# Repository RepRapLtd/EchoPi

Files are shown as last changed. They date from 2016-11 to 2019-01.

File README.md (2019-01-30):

# EchoPi

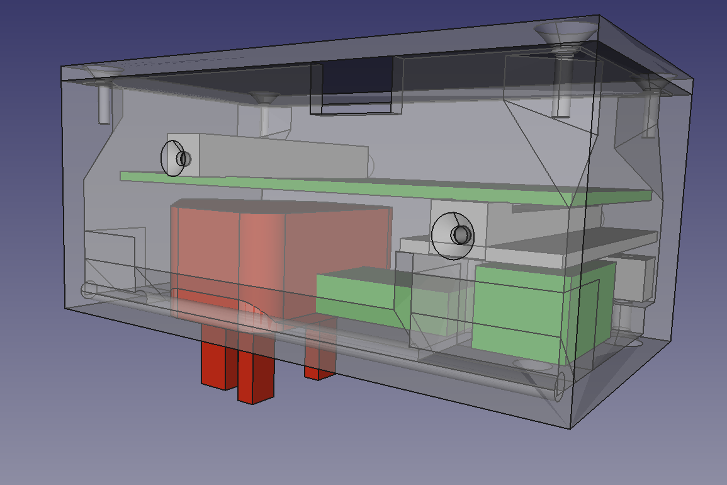
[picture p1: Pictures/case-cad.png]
FreeCAD design


This is a device that uses the Raspberry Pi Zero as a WeMo device to turn on mains-powered items in your home using the Amazon Echo/Echo-Dot and their Alexa voice-recognition system.

## Safety

This uses mains electricity.  Mains will kill you if you touch it.  So don't.

The maximum current that this can switch is 1 amp.  With 220-volt mains that means a maximum 200W load; with 110-volt mains that means a maximum 100 W load.  The device is designed with a fuse holder.  Fit this with a 1 A fuse.

Parents: we set no age limits here - there are twelve-year-olds who could have organised D-Day, and there are thirty-seven-year-olds who can't be trusted with a penknife.  But don't let your children experiment with this unless you are confident that they are responsible and sensible.

Realistically, you will probably want to operate this with the cover off when you are setting it up.  Plug everything in to a disconnected extension cable and connect everything up.  Then - without touching anything to do with the uncovered case - plug the extension into a wall socket and turn it on.  Turn off and unplug the wall socket before you touch anything again.

## Electronics

The Eagle (https://cadsoft.io/) circuit design is single sided with a few jumpers.  It is intended to be produced by milling, though you can etch it conventionally as well of course.

The device incorporates a mains USB charger (like this: https://www.amazon.co.uk/Quality-Charger-Blackberry-Love-Accessories/dp/B01M2XE8V9/ ; red in the picture above).  This both acts as the plug so the device can be plugged into a wall socket, and as a 5V supply for the Raspberry Pi Zero and the rest of the electronics.

You will have to hack the charger by attaching wires to the three mains connections inside and drilling holes to run them out of.  The neutral and earth run straight through the device to the mains output, and the live wire goes through the fuse and then the opto-isolated phototriac, which switches it on and off.   

## Mechanics

The FreeCAD (http://www.freecadweb.org/) case is designed to be 3D printed.  

## Software

See here to create a linux image on an SD card for the Pi Zero:

https://www.raspberrypi.org/documentation/installation/installing-images/linux.md

Boot up the Pi Zero.  Change it's name to something you want:

http://www.howtogeek.com/167195/how-to-change-your-raspberry-pi-or-other-linux-devices-hostname/

Set your timezone:

http://www.geeklee.co.uk/update-time-zone-on-raspberry-pi-with-raspbian/

Set your Pi to have a static IP address, giving it the same one for ethernet and WiFi (you're not going to use both at once):

https://www.modmypi.com/blog/how-to-give-your-raspberry-pi-a-static-ip-address-update

Setup your WiFi network and password:

https://learn.adafruit.com/adafruits-raspberry-pi-lesson-3-network-setup/setting-up-wifi-with-occidentalis

Next get and run the EchoPi software:

$ git clone https://github.com/RepRapLtd/EchoPi.git

$ cd EchoPi/Software

$ pip install -r requirements.txt

$ nohup python echopi.py > /dev/null &

Tell Alexa, "Alexa, discover my devices."

Say, "Alexa, turn off device," and, "Alexa device on," to switch the mains socket off and on.

The line in the Python echopi.py program that sets the Alexa name of the device is this one:

     TRIGGERS = {"device": 52000}

Change the "device" to any name you like, but it's best to choose easily-pronounceable dictionary words or well-known proper nouns.  That way the Alexa speech recognition will be most reliable.

This is intended to connect to your home network using WiFi, but (particularly with BT HomeHubs) getting your Echo/Echo-Dot to find the device can be tricky.  

Start by turning off all the annoying "features" of the BT hub: disable Smart Setup; don't synchronise 5 GHz WiFi with 2.4 GHz (keep the passwords the same, though, or you'll never remember, and ignore the password warning it gives you when you do this); turn off Extended UPnP security.

Then use a micro-USB-to-ether adapter to connect the Pi Zero by wire to your hub.  

Run the Python program and tell Alexa to discover your devices.  She should find "device" (or whatever you have called it).  Test that it works by turning the load on and off.

Then shut everything down and disconnect it.  Fit a micro-USB-WiFi adapter in place of the Ethernet and power everything up again.  You should be able to ssh into the Pi as before.

Ask Alexa to turn your device on.  If she sees it, great.  But if not, press and hold the Echo/Echo-dot button to put it into set-up mode and leave it for a minute or so, then press and hold it again to turn set-up off.  It should reconnect to your hub and then be able to turn your device on and off.

The "nohup python echopi.py > /dev/null &" command will run the Python program in the background and it will stay running until you re-boot the Pi.  If you want to see what it is doing, just run "python echopi.py" instead.  But this will die when you log out.

If the program is running in the background and you want to kill it and start again, type:

$ ps -ael | grep pyth

This will give something like:

  0 S  1000   868   834 41  80   0 -  4062 poll_s pts/0    00:00:02 python

The number of the Python process is the 868.  To stop process 868 type:

$ kill -9 868

## Useful Links

Turn a Pi into an Echo/Echo-Dot equivalent:

http://www.instructables.com/id/Hacking-the-Amazon-Echo/

WeMo - the protocol used:

https://www.wemo.com/

## Acknowledgements

This is an extended fork of Todd Medema's repository here:

https://github.com/toddmedema/echo

Many thanks to him.

It uses the Raspberry Pi Zero Eagle Library from here:

https://www.raspberrypi.org/forums/viewtopic.php?f=63&t=127228

So thanks to them too.

## Licence

GPL

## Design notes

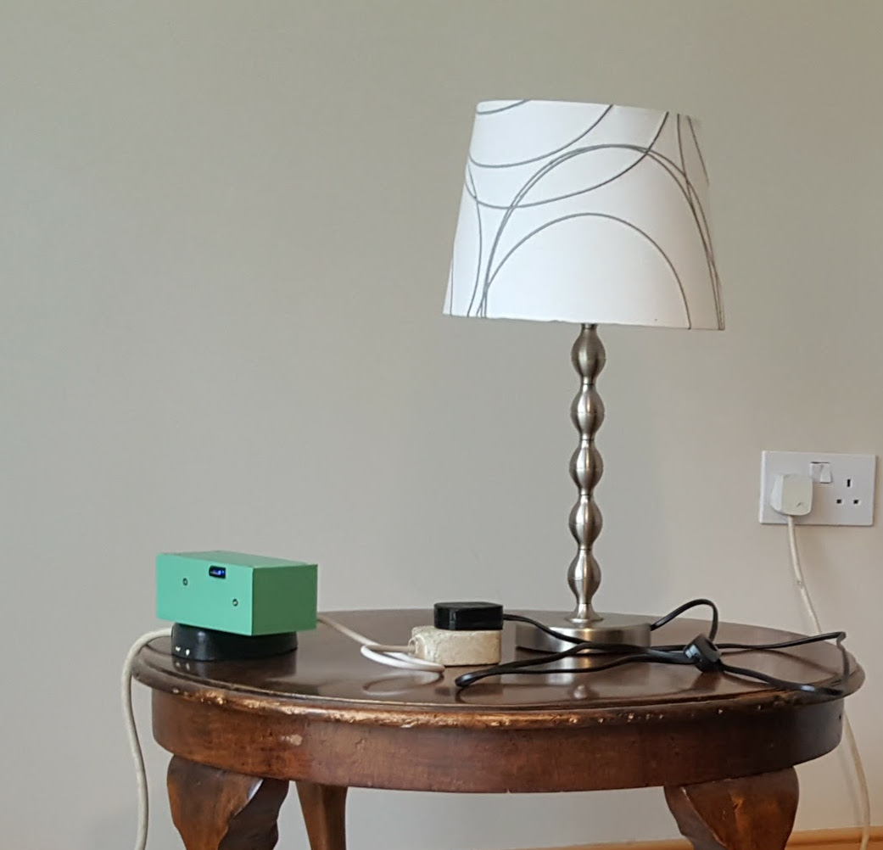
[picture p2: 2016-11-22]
Pictures/in-use.jpg

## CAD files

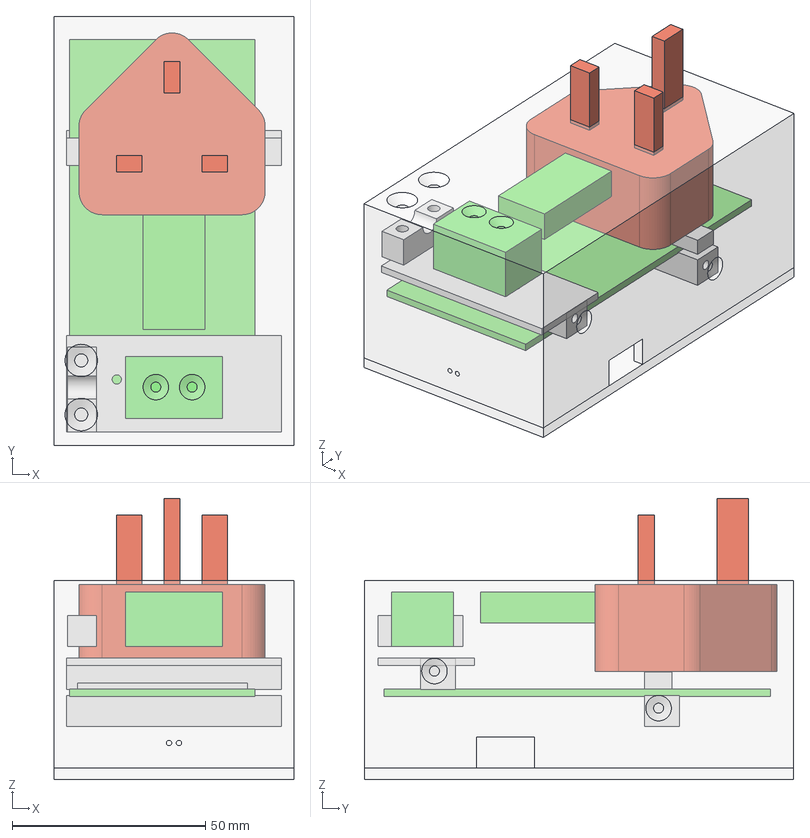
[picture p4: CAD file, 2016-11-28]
Mechanics/echopi.fcstd
62.0 x 111.0 x 72.8 mm
pcb
USB-A-plug
screw-con
cable-clamp
lid
13A-charger
pcb-support-2
spacer
pcb-support-1

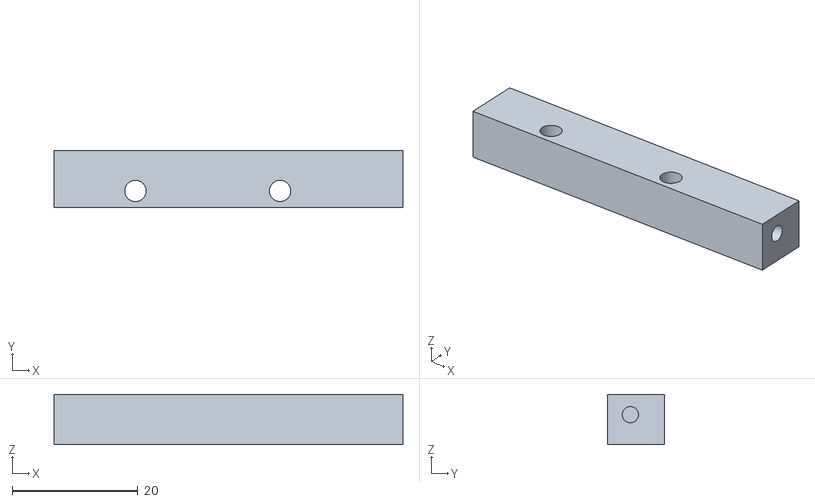
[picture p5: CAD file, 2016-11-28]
Mechanics/STLs/pcb-support-1.stl
55.5 x 9.00 x 8.00

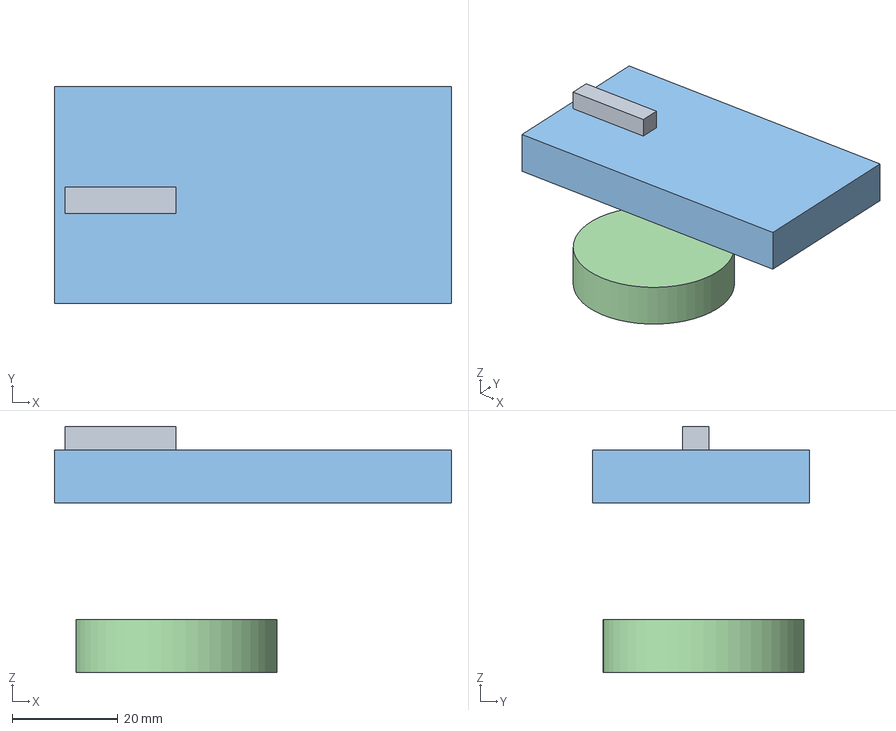
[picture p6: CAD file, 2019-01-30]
WeMos/Plug Box.fcstd
75.0 x 41.0 x 46.5 mm

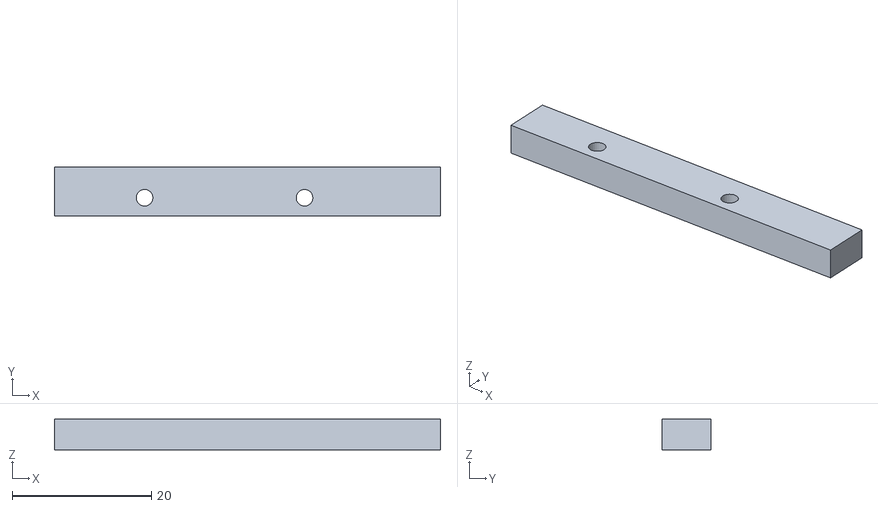
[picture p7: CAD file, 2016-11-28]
Mechanics/STLs/spacer.stl
55.5 x 7.00 x 4.40

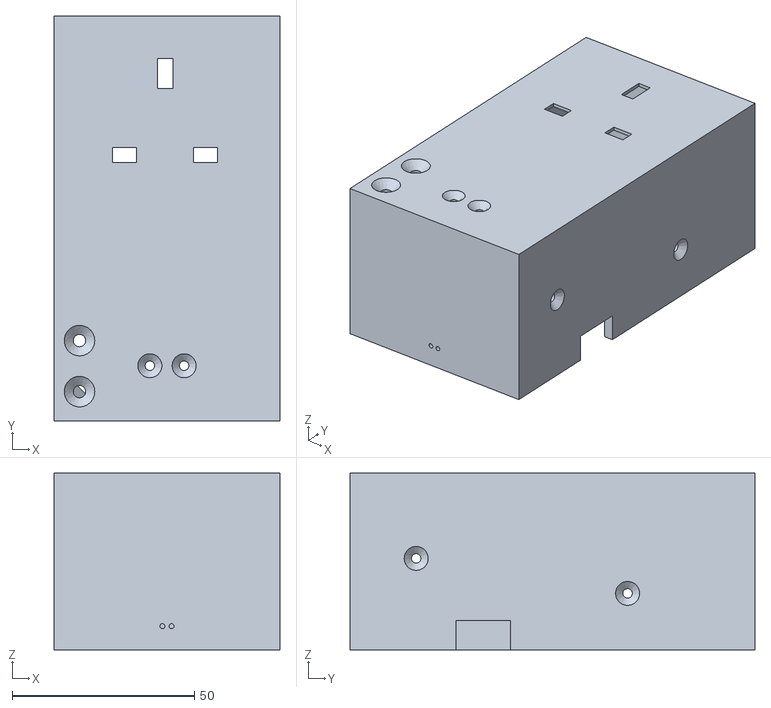
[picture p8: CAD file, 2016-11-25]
Mechanics/STLs/body.stl
62.0 x 111.0 x 48.5

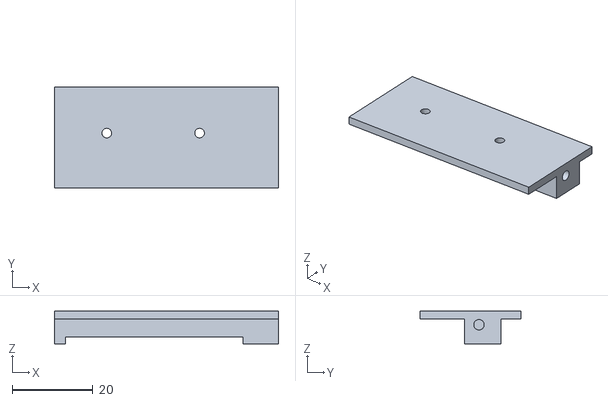
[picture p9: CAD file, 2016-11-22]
Mechanics/STLs/pcb-support-2.stl
55.5 x 25.0 x 8.17

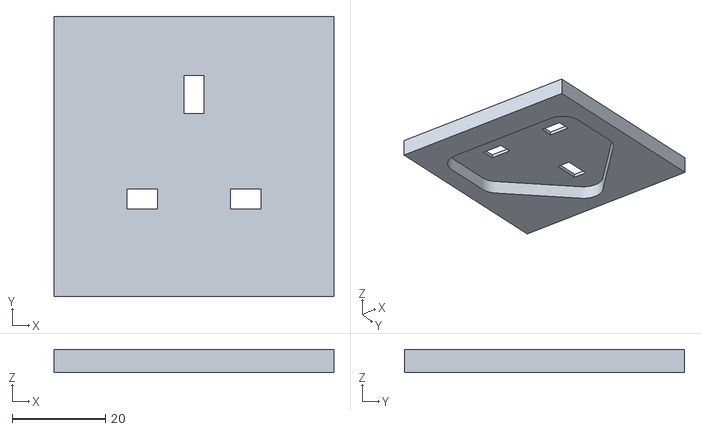
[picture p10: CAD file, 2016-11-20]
Mechanics/STLs/plug-test.stl
60.0 x 60.0 x 5.00

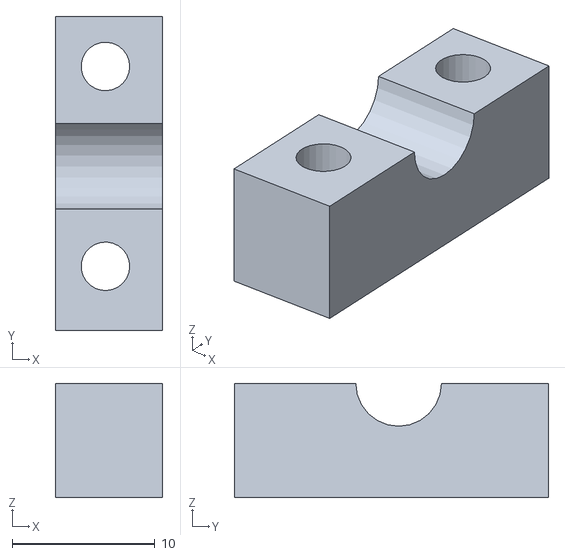
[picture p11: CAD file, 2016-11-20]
Mechanics/STLs/cable-clamp.stl
7.50 x 22.0 x 8.00

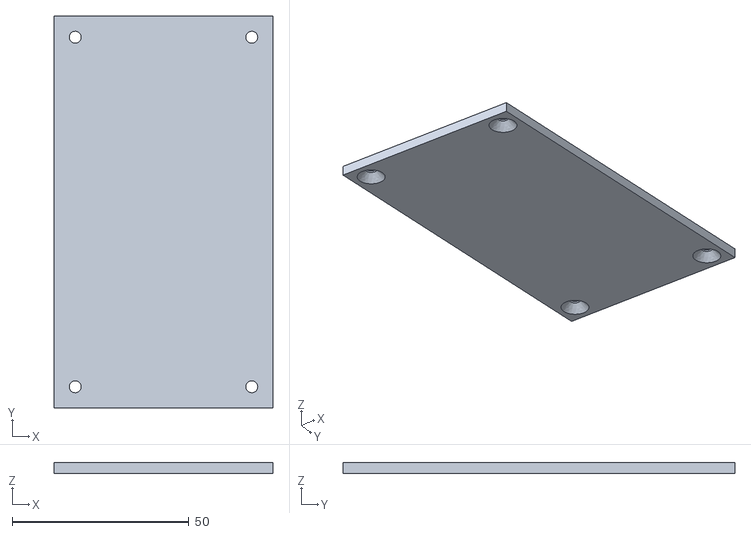
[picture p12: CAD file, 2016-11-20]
Mechanics/STLs/lid.stl
62.0 x 111.0 x 3.00

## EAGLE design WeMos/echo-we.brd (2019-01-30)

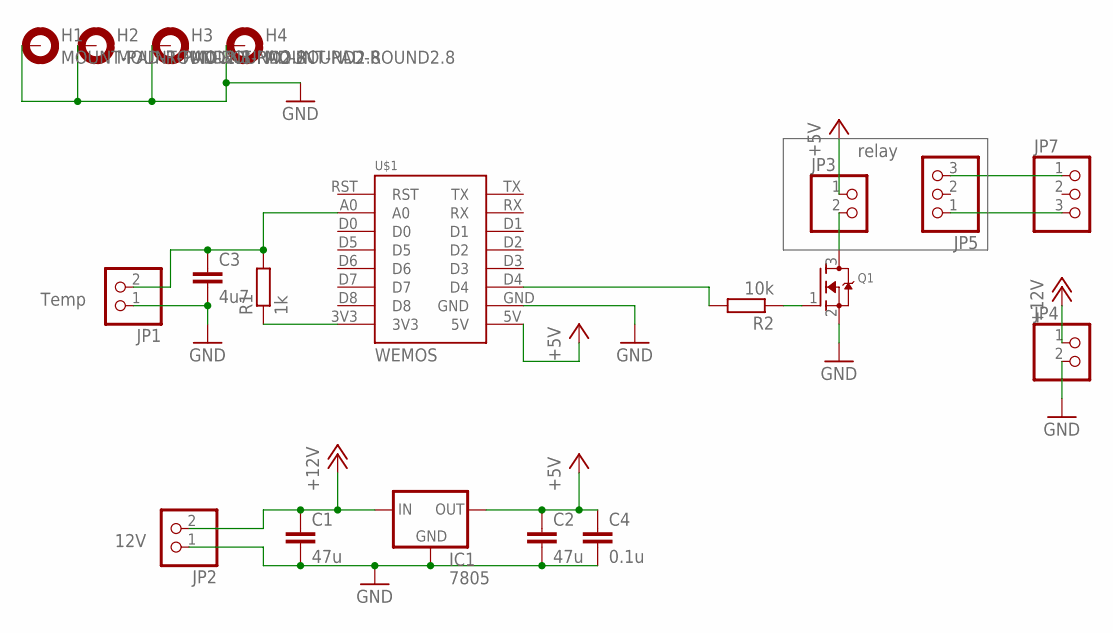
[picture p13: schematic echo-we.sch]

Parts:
C1, C2: 47u; C1206
C3: 4u7; C1206
C4: 0.1u; C1206
H1, H2, H3, H4: MOUNT-PAD-ROUND2.8; 2,8-PAD
IC1: 7805; 78XXS
JP1, JP2, JP3, JP4: PINHD-1X2; 1X02
JP5, JP7: PINHD-1X3; 1X03
Q1: MOSFET-NREFLOW; SOT23
R1: 1k; R0805
R2: 10k; R0805
U$1: WEMOS

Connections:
+5V: C2.1, C4.1, IC1.OUT, JP3.1, U$1.5V
+12V: C1.1, IC1.IN, JP2.2, JP4.1
GND: C1.2, C2.2, C3.2, C4.2, H1.B2,8, H2.B2,8, H3.B2,8, H4.B2,8, IC1.GND, JP1.1, JP2.1, JP4.2, Q1.2 (S), U$1.GND
unnamed: R1.1, U$1.3V3
unnamed: C3.1, JP1.2, R1.2, U$1.A0
unnamed: JP5.3, JP7.1
unnamed: JP5.1, JP7.3
unnamed: R2.2, U$1.D4
unnamed: Q1.1 (G), R2.1
unnamed: JP3.2, Q1.3 (D)

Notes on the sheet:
Temp
12V
relay

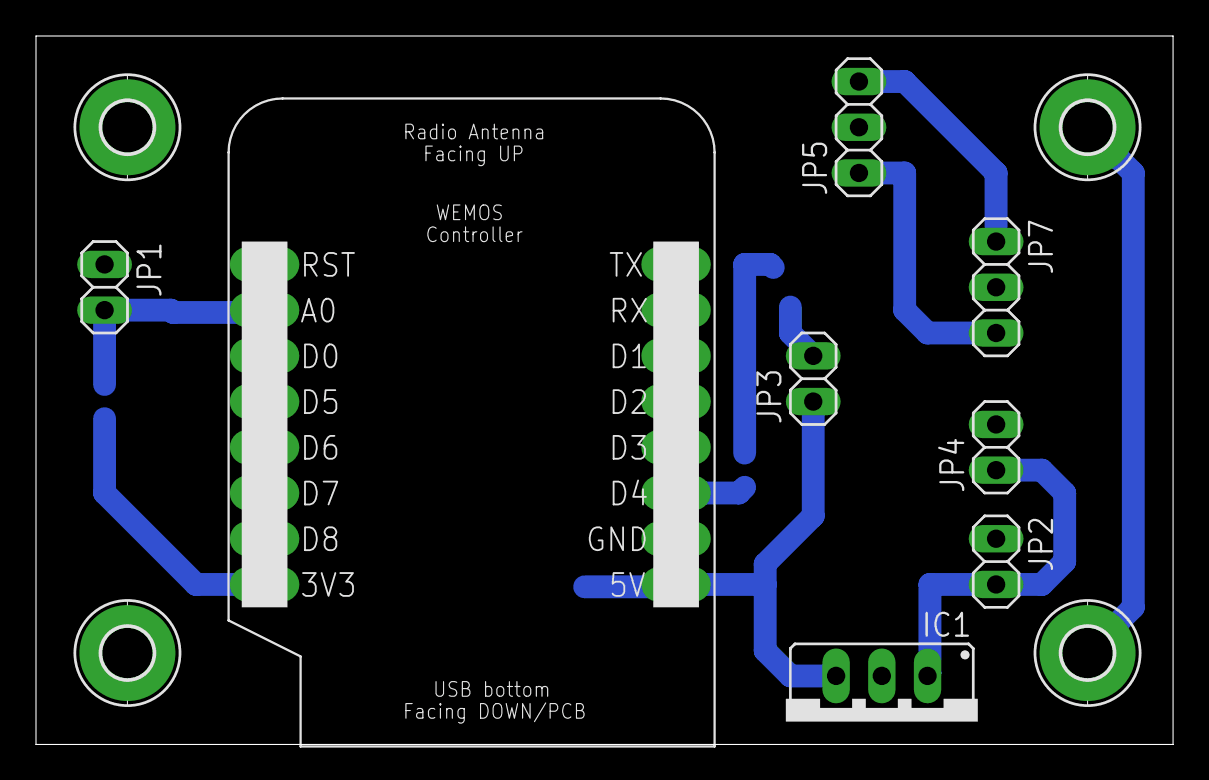
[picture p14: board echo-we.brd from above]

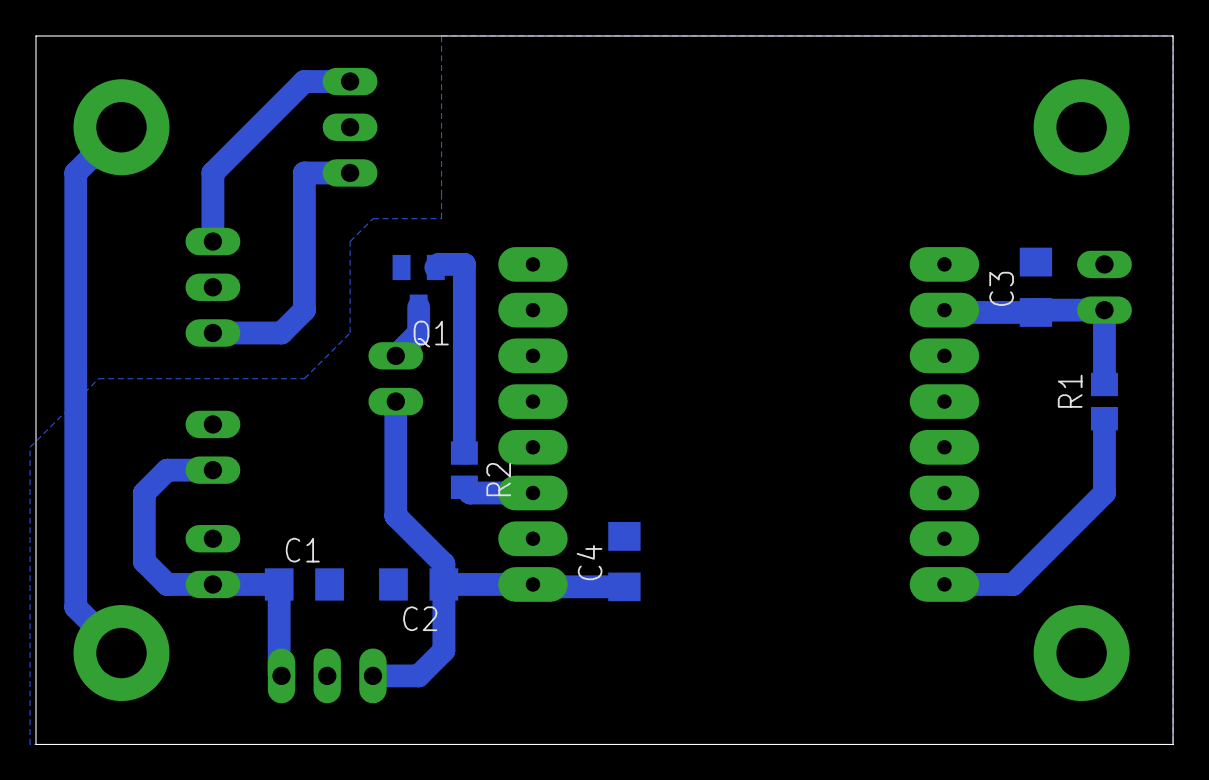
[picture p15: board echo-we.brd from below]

Board: 2 copper layers, 63.2 x 39.4 mm, 19 parts (7 on the bottom side), 10 nets.

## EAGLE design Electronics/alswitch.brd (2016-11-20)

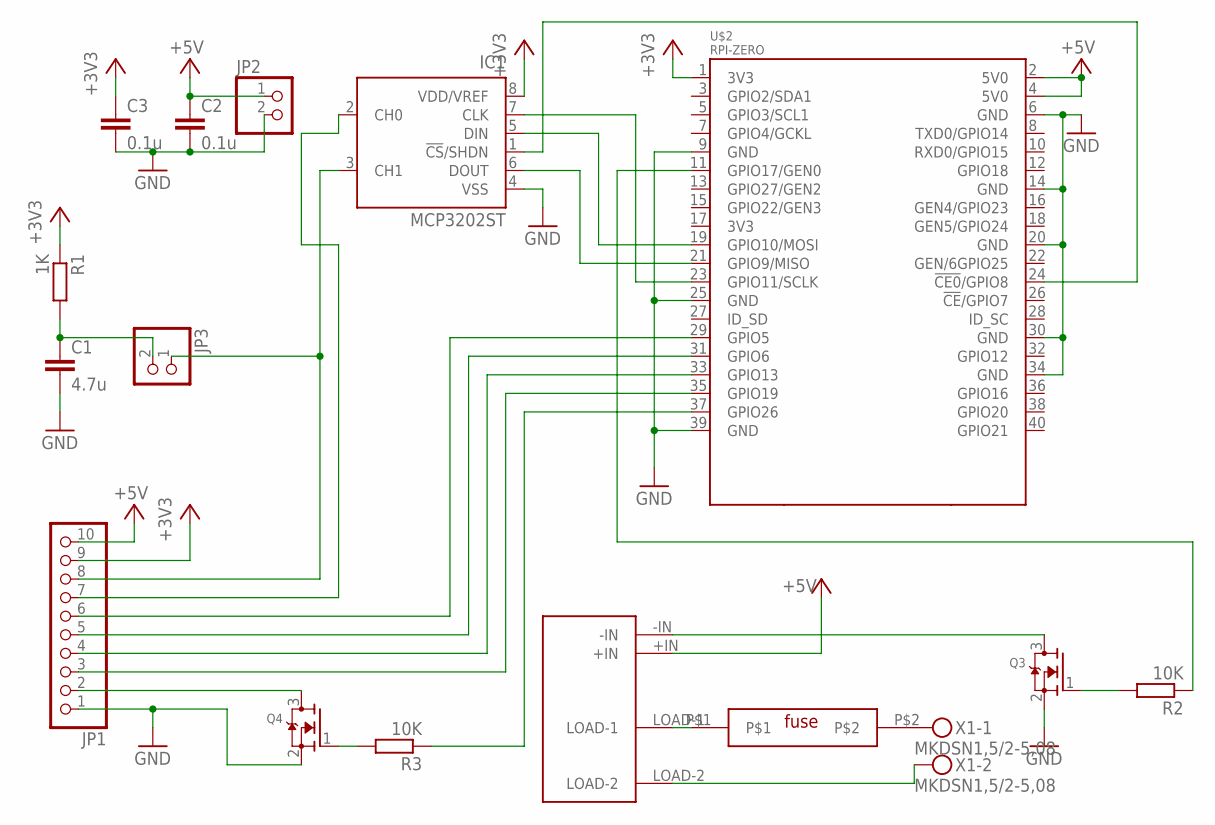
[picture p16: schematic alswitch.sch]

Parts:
C1: 4.7u; C1206
C2, C3: 0.1u; C1206
IC1: MCP3202ST; TSSOP8
JP1: PINHD-1X10; 1X10
JP2, JP3: PINHD-1X2; 1X02
Q3, Q4: MOSFET-NREFLOW; SOT23
R1: 1K; R0805
R2, R3: 10K; R0805
U$1: FUSE
U$2: RPI-ZERO; RASPBERRYPI_BASTELSTUBE_V13_RASPI_BOARD_B+_FULL
U$3: G3MC-201PL
X1: MKDSN1,5/2-5,08

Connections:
+3V3: C3.1, IC1.8 (VDD/VREF), JP1.9, R1.1, U$2.1 (3V3)
+5V: C2.1, JP1.10, JP2.1, U$2.2 (5V0), U$2.4 (5V0), U$3.+IN
GND: C1.2, C2.2, C3.2, IC1.4 (VSS), JP1.1, JP2.2, Q3.2 (S), Q4.2 (S), U$2.6 (GND), U$2.9 (GND), U$2.14 (GND), U$2.20 (GND), U$2.25 (GND), U$2.30 (GND), U$2.34 (GND), U$2.39 (GND)
unnamed: IC1.7 (CLK), U$2.23 (GPIO11/SCLK)
unnamed: Q3.3 (D), U$3.-IN
unnamed: R2.1, U$2.11 (GPIO17/GEN0)
unnamed: U$1.P$2, X1.1
unnamed: IC1.5 (DIN), U$2.19 (GPIO10/MOSI)
unnamed: IC1.6 (DOUT), U$2.21 (GPIO9/MISO)
unnamed: Q3.1 (G), R2.2
unnamed: JP1.6, U$2.29 (GPIO5)
unnamed: Q4.1 (G), R3.2
unnamed: JP1.3, U$2.35 (GPIO19)
unnamed: U$1.P$1, U$3.LOAD-1
unnamed: JP1.4, U$2.33 (GPIO13)
unnamed: JP1.5, U$2.31 (GPIO6)
unnamed: IC1.1 (!CS!/SHDN), U$2.24 (!CE0!/GPIO8)
unnamed: IC1.3 (CH1), JP1.8, JP3.1
unnamed: IC1.2 (CH0), JP1.7
unnamed: C1.1, JP3.2, R1.2
unnamed: JP1.2, Q4.3 (D)
unnamed: R3.1, U$2.37 (GPIO26)
unnamed: U$3.LOAD-2, X1.2

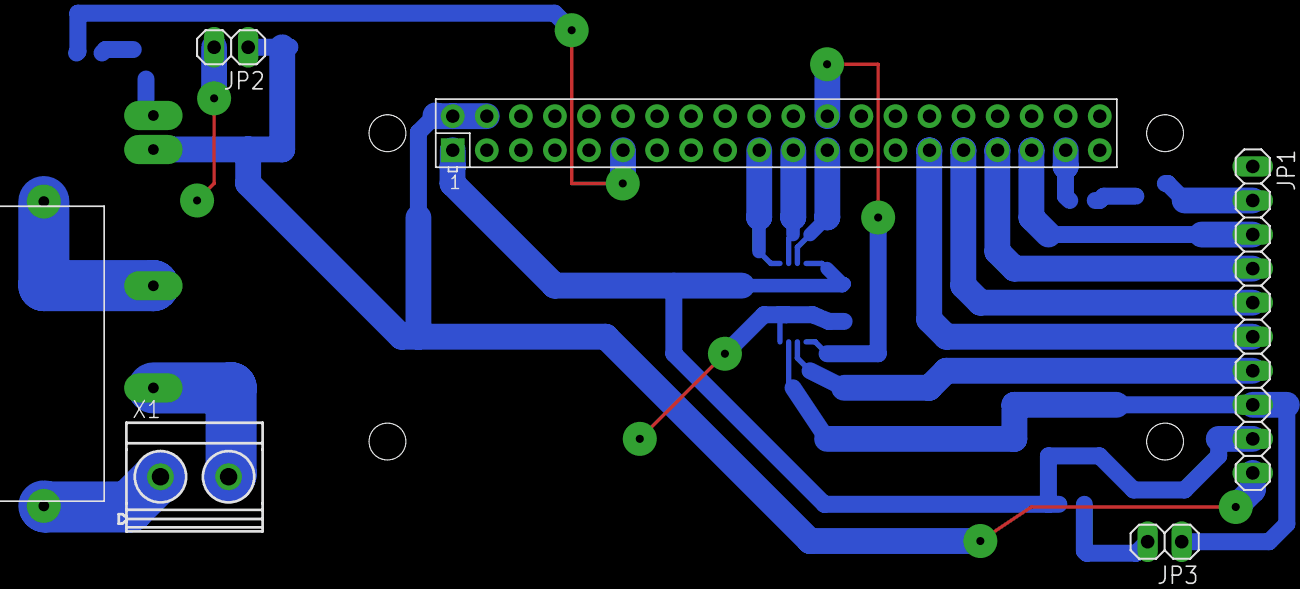
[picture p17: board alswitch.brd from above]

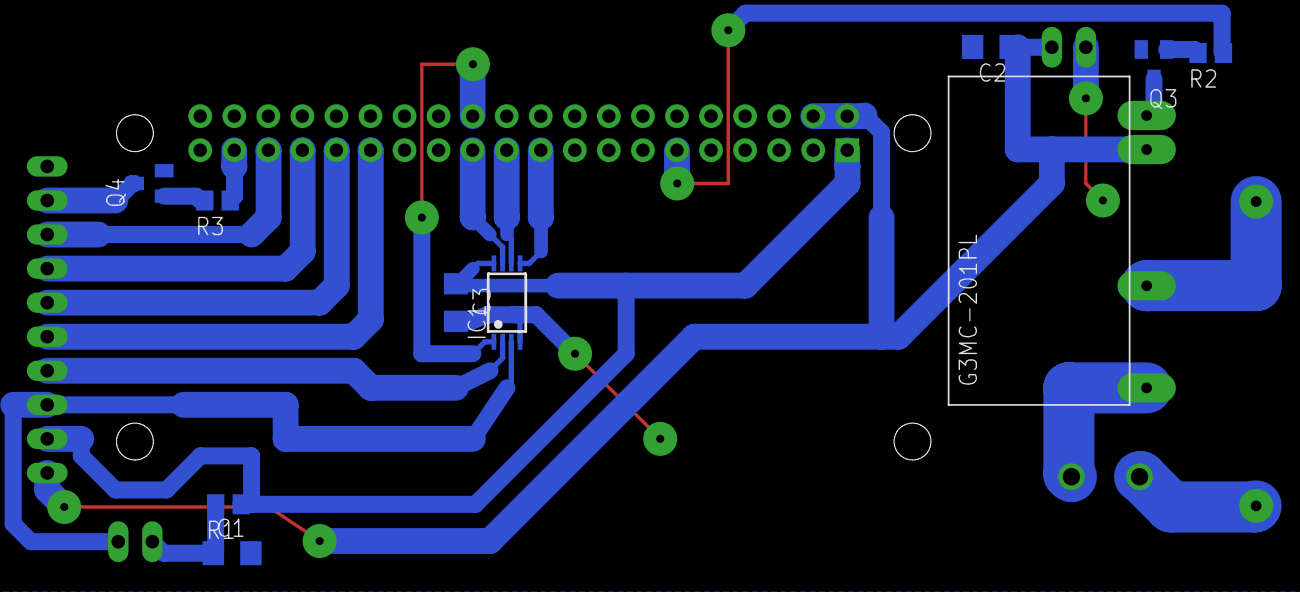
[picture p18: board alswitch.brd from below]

Board: 2 copper layers, 16 parts (10 on the bottom side), 23 nets.

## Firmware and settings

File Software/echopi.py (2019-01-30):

""" fauxmo_minimal.py - Fabricate.IO

    This is a demo python file showing what can be done with the debounce_handler.
    The handler prints True when you say "Alexa, device on" and False when you say
    "Alexa, device off".

    If you have two or more Echos, it only handles the one that hears you more clearly.
    You can have an Echo per room and not worry about your handlers triggering for
    those other rooms.

    The IP of the triggering Echo is also passed into the act() function, so you can
    do different things based on which Echo triggered the handler.
"""

import fauxmo
import logging
import time
from gpiozero import LED

from debounce_handler import debounce_handler
led = LED(17)

logging.basicConfig(level=logging.DEBUG)

class device_handler(debounce_handler):
    """Publishes the on/off state requested,
       and the IP address of the Echo making the request.
    """
    TRIGGERS = {"device": 52000}

    def act(self, client_address, state):
        if state:
          led.on()
        else:
          led.off()
        print "State", state, "from client @", client_address
        return True

if __name__ == "__main__":
    # Startup the fauxmo server
    fauxmo.DEBUG = True
    p = fauxmo.poller()
    u = fauxmo.upnp_broadcast_responder()
    u.init_socket()
    p.add(u)

    # Register the device callback as a fauxmo handler
    d = device_handler()
    for trig, port in d.TRIGGERS.items():
        fauxmo.fauxmo(trig, u, p, None, port, d)
    
    # Loop and poll for incoming Echo requests
    logging.debug("Entering fauxmo polling loop")
    while True:
        try:
            # Allow time for a ctrl-c to stop the process
            p.poll(100)
            time.sleep(0.1)
        except Exception, e:
            logging.critical("Critical exception: " + str(e))
            break

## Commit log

2016-11-20 First commit. Added electronics and casing designs. Reorganised files.
    [13A-plug.fcstd, alswitch.brd, alswitch.sch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]
2016-11-20 Python/Pi switche program added.
2016-11-20 CAD file tidying.
    [13A-plug.fcstd]
2016-11-20 Updating STL files
    [body.stl, pcb-support-1.stl, pcb-support-2.stl]
2016-11-21 Added link for mains charger.
2016-11-21 Thermistor holes in body added.
    [13A-plug.fcstd, body.stl]
2016-11-22 Added more pictures.
    [13A-plug.fcstd, body.stl]
2016-11-22 Updating STLs
    [body.stl, echopi.fcstd, pcb-support-2.stl]
2016-11-25 Small improvements to the mechanical design.
    [13A-plug.fcstd, body.stl, echopi.fcstd]
2016-11-28 Improved mechanics. Updated README.
    [echopi.fcstd, pcb-support-1.stl, spacer.stl]
2016-12-14 Added switchon.py to test the mains triac
2019-01-30 File tidying.
    [Plug Box.fcstd, body.stl, cable-clamp.stl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]
